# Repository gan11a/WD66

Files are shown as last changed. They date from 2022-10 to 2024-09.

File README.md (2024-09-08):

# WD66 ver 0.1

# As of 12/21/2023 PCB is finished, and tested.

# Witch Doctor 66 is a 65% mechanical keyboard, with layout similar to Leopold FC660M. The idea is to make it compatible with Leopold's case if you don't solder in 2 switches. I want this project to live beyond group buy (if it will ever happen), hence secondary function of PCB to be a drop-in replacement into Leopold. You can find pictures of implemented layouts and layouts planed below, as well as pictures of the PCB.
<h2>
<p align="center">
Layouts:
</p>
</h2>


<h2>
<p align="center">
PCB renders:
</p>
</h2>
<p align="center">


</p>
<h2>
<p align="center">
Photos:
</p>
</h2>
<p align="center">


</p>

# You are welcome to fork, modify and produce it on your own, that said I would like to be in the know about production for profit (dm me on discord: gan1a#5261); also don't be an a*s, don't erase solder mask art))). Rough to-do list is below.

# For ongoing development and planed features please refer to the [issues](https://github.com/gan11a/WD66/issues) page of WD66 Repository.

# Huge thanks to my friends FOXY and ANV3R for supporting me through this project.

# By <a href="https://11customs.com">11customs</a>

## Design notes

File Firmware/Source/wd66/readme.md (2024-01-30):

# wd66

wd66

# default layout:
layout

* Keyboard Maintainer: [11customs](https://github.com/gan11a)
* Hardware Supported: wd66_rev1
* Hardware Availability: *shop not running yet*

Make example for this keyboard (after setting up your build environment):

    make wd66:default

Flashing example for this keyboard:

    make wd66:default:flash

See the [build environment setup](https://docs.qmk.fm/#/getting_started_build_tools) and the [make instructions](https://docs.qmk.fm/#/getting_started_make_guide) for more information. Brand new to QMK? Start with our [Complete Newbs Guide](https://docs.qmk.fm/#/newbs).

## Bootloader

Enter the bootloader in 3 ways:

* **Bootmagic reset**: *not implemented yet*
* **Physical reset button**: Briefly press the button on the back of the PCB near the spacebar.
* **Keycode in layout**: *not implemented yet*

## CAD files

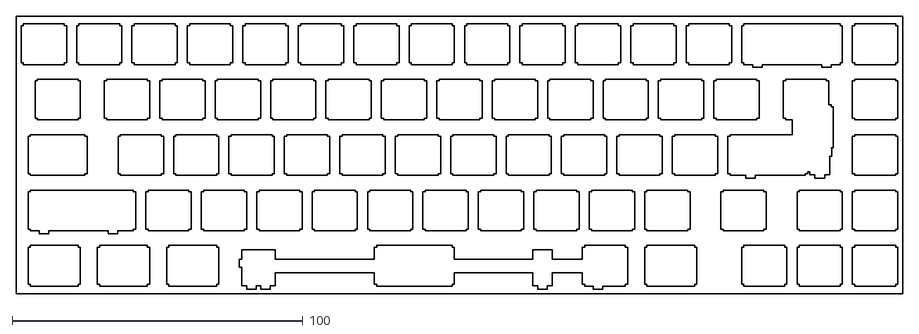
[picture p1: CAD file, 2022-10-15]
Plate/84455f1f9d11c78b356b71624a2b0eeafa77bcbd_switch.dxf
304.8 x 95.2

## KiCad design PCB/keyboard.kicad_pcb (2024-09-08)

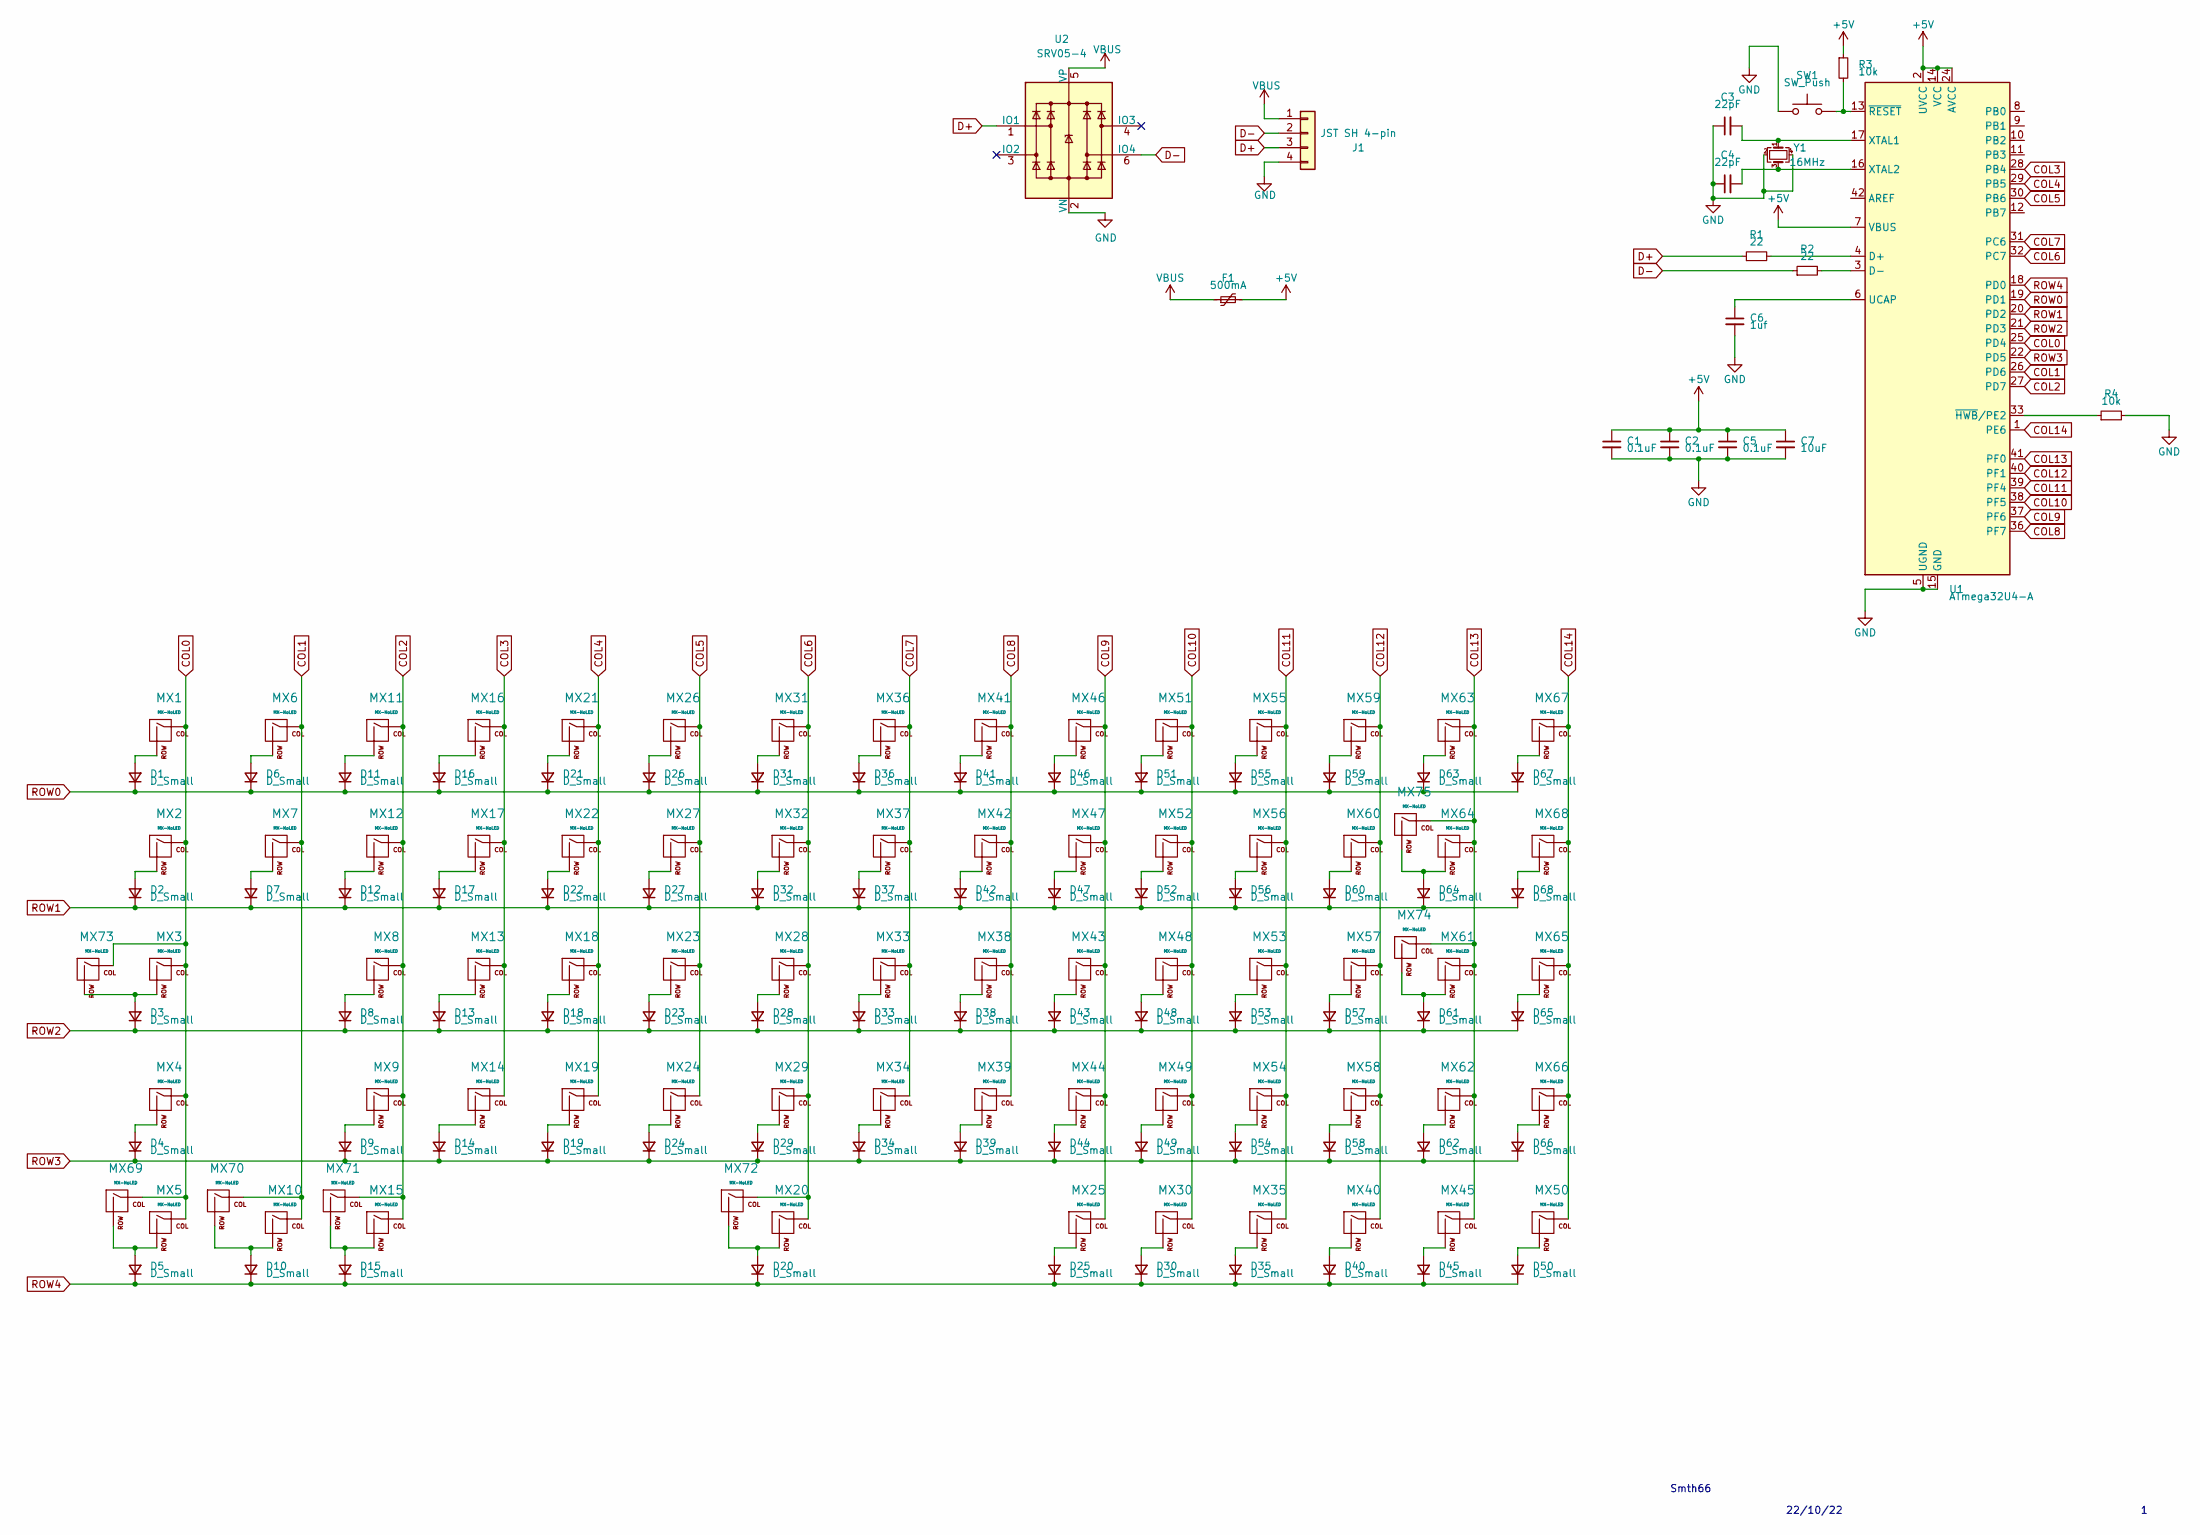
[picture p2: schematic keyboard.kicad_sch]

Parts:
C1, C2, C5: 0.1uF; C_0805_2012Metric
C3, C4: 22pF; C_0805_2012Metric
C6: 1uf; C_0805_2012Metric
C7: 10uF; C_0805_2012Metric
D1, D2, D3, D4, D5, D6, D7, D8, D9, D10, D11, D12, D13, D14, D15, D16, D17, D18, D19, D20, D21, D22, D23, D24, D25, D26, D27, D28, D29, D30, D31, D32, D33, D34, D35, D36, D37, D38, D39, D40, D41, D42, D43, D44, D45, D46, D47, D48, D49, D50, D51, D52, D53, D54, D55, D56, D57, D58, D59, D60, D61, D62, D63, D64, D65, D66, D67, D68: D_Small; D_SOD-123
F1: 500mA; Fuse_1206_3216Metric
J1: JST SH 4-pin; JST_SH_SM04B-SRSS-TB_1x04-1MP_P1.00mm_Horizontal; LCSC Part # C160404
MX1, MX6, MX7, MX8, MX9, MX10, MX11, MX12, MX13, MX14, MX16, MX17, MX18, MX19, MX21, MX22, MX23, MX24, MX26, MX27, MX28, MX29, MX31, MX32, MX33, MX34, MX36, MX37, MX38, MX39, MX40, MX41, MX42, MX43, MX44, MX45, MX46, MX47, MX48, MX49, MX50, MX51, MX52, MX53, MX54, MX55, MX56, MX57, MX59, MX60, MX62, MX65, MX66, MX67, MX68, MX70, MX75: MX-NoLED; MXOnly-1U-NoLED
MX2, MX64, MX69, MX71: MX-NoLED; MXOnly-1.5U-NoLED
MX3: MX-NoLED; MXOnly-1.75U-NoLED
MX4, MX58, MX61: MX-NoLED; MXOnly-2.25U-NoLED
MX5, MX15, MX25, MX30, MX35: MX-NoLED; MXOnly-1.25U-NoLED
MX20: MX-NoLED; MXOnly-6.25U-ReversedStabilizers-NoLED
MX63: MX-NoLED; MXOnly-2U-NoLED
MX72: MX-NoLED; MXOnly-7U-ReversedStabilizers-NoLED
MX73: MX-NoLED; SW_MX_1.75u_stp
MX74: MX-NoLED; MXOnly-ISO-ReversedStabilizers-NoLED
R1, R2: 22; R_0805_2012Metric
R3, R4: 10k; R_0805_2012Metric
SW1: SW_Push; SKQG-1155865
U1: ATmega32U4-A; TQFP-44_10x10mm_P0.8mm
U2: SRV05-4; SOT-23-6-routable; LCSC Part # C85364
Y1: 16MHz; Crystal_SMD_3225-4Pin_3.2x2.5mm

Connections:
+5V: C1.1, C2.1, C5.1, C7.1, F1.2, R3.1, U1.2 (UVCC), U1.7 (VBUS), U1.14 (VCC), U1.24 (AVCC), U1.34 (VCC), U1.44 (AVCC)
COL0: MX1.1 (COL), MX2.1 (COL), MX3.1 (COL), MX4.1 (COL), MX5.1 (COL), MX69.1 (COL), MX73.1 (COL), U1.25 (PD4)
COL1: MX6.1 (COL), MX7.1 (COL), MX10.1 (COL), MX70.1 (COL), U1.26 (PD6)
COL2: MX8.1 (COL), MX9.1 (COL), MX11.1 (COL), MX12.1 (COL), MX15.1 (COL), MX71.1 (COL), U1.27 (PD7)
COL3: MX13.1 (COL), MX14.1 (COL), MX16.1 (COL), MX17.1 (COL), U1.28 (PB4)
COL4: MX18.1 (COL), MX19.1 (COL), MX21.1 (COL), MX22.1 (COL), U1.29 (PB5)
COL5: MX23.1 (COL), MX24.1 (COL), MX26.1 (COL), MX27.1 (COL), U1.30 (PB6)
COL6: MX20.1 (COL), MX28.1 (COL), MX29.1 (COL), MX31.1 (COL), MX32.1 (COL), MX72.1 (COL), U1.32 (PC7)
COL7: MX33.1 (COL), MX34.1 (COL), MX36.1 (COL), MX37.1 (COL), U1.31 (PC6)
COL8: MX38.1 (COL), MX39.1 (COL), MX41.1 (COL), MX42.1 (COL), U1.36 (PF7)
COL9: MX25.1 (COL), MX43.1 (COL), MX44.1 (COL), MX46.1 (COL), MX47.1 (COL), U1.37 (PF6)
COL10: MX30.1 (COL), MX48.1 (COL), MX49.1 (COL), MX51.1 (COL), MX52.1 (COL), U1.38 (PF5)
COL11: MX35.1 (COL), MX53.1 (COL), MX54.1 (COL), MX55.1 (COL), MX56.1 (COL), U1.39 (PF4)
COL12: MX40.1 (COL), MX57.1 (COL), MX58.1 (COL), MX59.1 (COL), MX60.1 (COL), U1.40 (PF1)
COL13: MX45.1 (COL), MX61.1 (COL), MX62.1 (COL), MX63.1 (COL), MX64.1 (COL), MX74.1 (COL), MX75.1 (COL), U1.41 (PF0)
COL14: MX50.1 (COL), MX65.1 (COL), MX66.1 (COL), MX67.1 (COL), MX68.1 (COL), U1.1 (PE6)
GND: C1.2, C2.2, C3.1, C4.1, C5.2, C6.2, C7.2, J1.4, R4.2, SW1.1, U1.5 (UGND), U1.15 (GND), U1.23 (GND), U1.35 (GND), U1.43 (GND), U2.2 (VN), Y1.2, Y1.4
unnamed: D1.2 (A), MX1.2 (ROW)
unnamed: D2.2 (A), MX2.2 (ROW)
unnamed: D3.2 (A), MX3.2 (ROW), MX73.2 (ROW)
unnamed: D4.2 (A), MX4.2 (ROW)
unnamed: D5.2 (A), MX5.2 (ROW), MX69.2 (ROW)
unnamed: D6.2 (A), MX6.2 (ROW)
unnamed: D7.2 (A), MX7.2 (ROW)
unnamed: D8.2 (A), MX8.2 (ROW)
unnamed: D9.2 (A), MX9.2 (ROW)
unnamed: D10.2 (A), MX10.2 (ROW), MX70.2 (ROW)
unnamed: D11.2 (A), MX11.2 (ROW)
unnamed: D12.2 (A), MX12.2 (ROW)
unnamed: D13.2 (A), MX13.2 (ROW)
unnamed: D14.2 (A), MX14.2 (ROW)
unnamed: D15.2 (A), MX15.2 (ROW), MX71.2 (ROW)
unnamed: D16.2 (A), MX16.2 (ROW)
unnamed: D17.2 (A), MX17.2 (ROW)
unnamed: D18.2 (A), MX18.2 (ROW)
unnamed: D19.2 (A), MX19.2 (ROW)
unnamed: D20.2 (A), MX20.2 (ROW), MX72.2 (ROW)
unnamed: D21.2 (A), MX21.2 (ROW)
unnamed: D22.2 (A), MX22.2 (ROW)
unnamed: D23.2 (A), MX23.2 (ROW)
unnamed: D24.2 (A), MX24.2 (ROW)
unnamed: D25.2 (A), MX25.2 (ROW)
unnamed: D26.2 (A), MX26.2 (ROW)
unnamed: D27.2 (A), MX27.2 (ROW)
unnamed: D28.2 (A), MX28.2 (ROW)
unnamed: D29.2 (A), MX29.2 (ROW)
unnamed: D30.2 (A), MX30.2 (ROW)
unnamed: D31.2 (A), MX31.2 (ROW)
unnamed: D32.2 (A), MX32.2 (ROW)
unnamed: D33.2 (A), MX33.2 (ROW)
unnamed: D34.2 (A), MX34.2 (ROW)
unnamed: D35.2 (A), MX35.2 (ROW)
unnamed: D36.2 (A), MX36.2 (ROW)
unnamed: D37.2 (A), MX37.2 (ROW)
unnamed: D38.2 (A), MX38.2 (ROW)
unnamed: D39.2 (A), MX39.2 (ROW)
unnamed: D40.2 (A), MX40.2 (ROW)
unnamed: D41.2 (A), MX41.2 (ROW)
unnamed: D42.2 (A), MX42.2 (ROW)
unnamed: D43.2 (A), MX43.2 (ROW)
unnamed: D44.2 (A), MX44.2 (ROW)
unnamed: D45.2 (A), MX45.2 (ROW)
unnamed: D46.2 (A), MX46.2 (ROW)
unnamed: D47.2 (A), MX47.2 (ROW)
unnamed: D48.2 (A), MX48.2 (ROW)
unnamed: D49.2 (A), MX49.2 (ROW)
unnamed: D50.2 (A), MX50.2 (ROW)
unnamed: D51.2 (A), MX51.2 (ROW)
unnamed: D52.2 (A), MX52.2 (ROW)
unnamed: D53.2 (A), MX53.2 (ROW)
unnamed: D54.2 (A), MX54.2 (ROW)
unnamed: D55.2 (A), MX55.2 (ROW)
unnamed: D56.2 (A), MX56.2 (ROW)
unnamed: D57.2 (A), MX57.2 (ROW)
unnamed: D58.2 (A), MX58.2 (ROW)
unnamed: D59.2 (A), MX59.2 (ROW)
unnamed: D60.2 (A), MX60.2 (ROW)
unnamed: D61.2 (A), MX61.2 (ROW), MX74.2 (ROW)
unnamed: D62.2 (A), MX62.2 (ROW)
unnamed: D63.2 (A), MX63.2 (ROW)
unnamed: D64.2 (A), MX64.2 (ROW), MX75.2 (ROW)
unnamed: D65.2 (A), MX65.2 (ROW)
unnamed: D66.2 (A), MX66.2 (ROW)
unnamed: D67.2 (A), MX67.2 (ROW)
unnamed: D68.2 (A), MX68.2 (ROW)
unnamed: C6.1, U1.6 (UCAP)
unnamed: C3.2, U1.17 (XTAL1), Y1.1
unnamed: C4.2, U1.16 (XTAL2), Y1.3
unnamed: R4.1, U1.33 (~HWB/PE2)
unnamed: R3.2, SW1.2, U1.13 (~RESET)
ROW0: D1.1 (K), D6.1 (K), D11.1 (K), D16.1 (K), D21.1 (K), D26.1 (K), D31.1 (K), D36.1 (K), D41.1 (K), D46.1 (K), D51.1 (K), D55.1 (K), D59.1 (K), D63.1 (K), D67.1 (K), U1.19 (PD1)
ROW1: D2.1 (K), D7.1 (K), D12.1 (K), D17.1 (K), D22.1 (K), D27.1 (K), D32.1 (K), D37.1 (K), D42.1 (K), D47.1 (K), D52.1 (K), D56.1 (K), D60.1 (K), D64.1 (K), D68.1 (K), U1.20 (PD2)
ROW2: D3.1 (K), D8.1 (K), D13.1 (K), D18.1 (K), D23.1 (K), D28.1 (K), D33.1 (K), D38.1 (K), D43.1 (K), D48.1 (K), D53.1 (K), D57.1 (K), D61.1 (K), D65.1 (K), U1.21 (PD3)
ROW3: D4.1 (K), D9.1 (K), D14.1 (K), D19.1 (K), D24.1 (K), D29.1 (K), D34.1 (K), D39.1 (K), D44.1 (K), D49.1 (K), D54.1 (K), D58.1 (K), D62.1 (K), D66.1 (K), U1.22 (PD5)
ROW4: D5.1 (K), D10.1 (K), D15.1 (K), D20.1 (K), D25.1 (K), D30.1 (K), D35.1 (K), D40.1 (K), D45.1 (K), D50.1 (K), U1.18 (PD0)
VBUS: F1.1, J1.1, U2.5 (VP)

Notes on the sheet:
Smth66
22/10/22

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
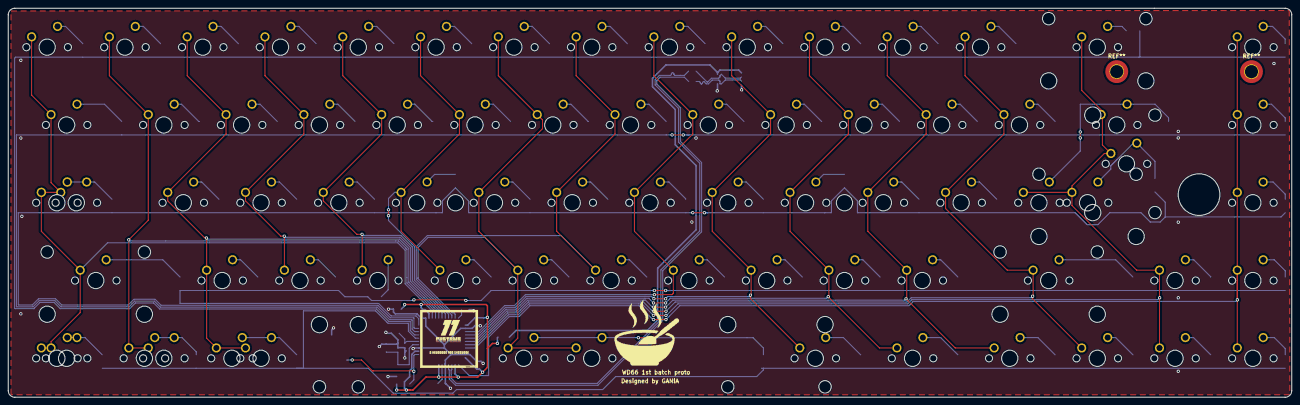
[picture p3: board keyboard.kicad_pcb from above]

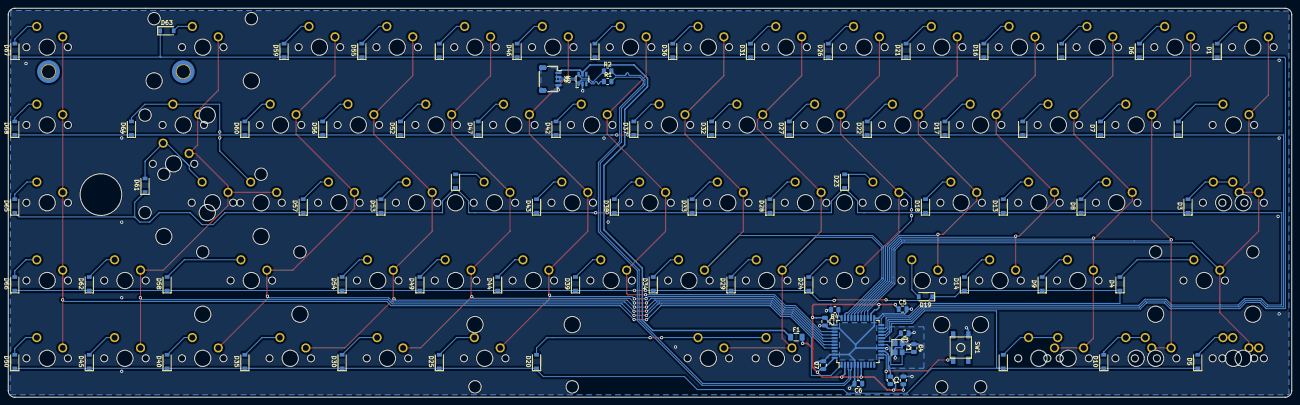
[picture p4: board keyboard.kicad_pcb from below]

Board: 2 copper layers, 314.3 x 95.3 mm, 160 parts (85 on the bottom side), 98 nets.

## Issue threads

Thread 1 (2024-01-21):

Big stand-off hole doesn't align with the stand-off on fc660m case.

gan11a, 2024-01-21:
>Title

gan11a, 2024-01-26:
Moved the hole

Closed 2024-01-26.

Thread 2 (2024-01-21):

Daughterboard doesn't have any mounting and is too thick for fc660m implementation.

gan11a, 2024-01-21:
> Title
Refer to personal obsidian doc for possible solution and other documentation.

gan11a, 2024-01-26:
Added a cutout for daughterboard

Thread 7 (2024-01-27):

Rework the hole firmware and add to QMK

gan11a, 2024-01-27:
>title

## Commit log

2022-10-22 Changed PCB Design
    [keyboard.kicad_pcb]
2022-10-22 fixed pcb folder
    [Soyuz65.kicad_pcb]
2022-10-22 configured footprints
    [keyboard.kicad_pcb, keyboard.kicad_sch]
2022-10-22 created MCU schematic
    [keyboard.kicad_sch]
2022-10-23 added USB and Switch to schematic
    [keyboard.kicad_sch]
2022-10-23 added switch grid to schematic
    [keyboard.kicad_sch]
2022-11-02 Finnished Schematic????
    [keyboard.kicad_sch]
2022-11-04 Started pcb development
    [keyboard.kicad_pcb]
2022-11-04 still working on pcb
2022-11-05 fixed footprints
    [keyboard.kicad_pcb, keyboard.kicad_sch]
2022-11-05 PCB work in progress
    [keyboard.kicad_pcb, keyboard.kicad_sch]
2022-11-06 mocked up pcb
    [keyboard.kicad_pcb]
2022-11-08 updated schematic to work with unified daughterboard
    [keyboard.kicad_sch]
2022-11-10 changed pcb to work with unified daughterboard
    [keyboard.kicad_pcb, keyboard.kicad_sch]
2022-11-20 Working on traces
    [keyboard.kicad_pcb, keyboard.kicad_sch]
2022-11-21 finnished traces
    [keyboard.kicad_pcb, keyboard.kicad_sch]
2022-11-26 Finished PCB designed, still not tested
    [keyboard.kicad_pcb]
2022-12-06 added holes for center standoffs
    [keyboard.kicad_pcb]
2022-12-06 updated silkscreen
    [keyboard.kicad_pcb]
2022-12-27 started redoing wiring
    [keyboard.kicad_pcb, keyboard.kicad_sch]
2022-12-27 all new pretty wiring
    [keyboard.kicad_pcb, keyboard.kicad_sch]
2022-12-29 added a hole
2023-01-07 smoothed out the wiring
2023-01-09 Redid wiring again
    [keyboard.kicad_sch]
2023-01-09 Differential pair done
    [keyboard.kicad_sch]
2023-01-16 started reworking wiring (again), only mx footprints now
    [keyboard.kicad_sch]
2023-01-16 redid wiring (again) no checks yet
    [keyboard.kicad_pcb, keyboard.kicad_sch]
2023-01-17 still working on wiring
    [keyboard.kicad_pcb]
2023-01-19 finnished implementing layouts
    [keyboard.kicad_pcb]
2023-01-23 relocated JST
    [keyboard.kicad_pcb]
2023-01-28 trying production
    [keyboard.kicad_pcb]
2023-12-21 production files and last small changes to v0.1
    [keyboard-CuBottom.gbr, keyboard-CuTop.gbr, keyboard-EdgeCuts.gbr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]
2024-01-26 started fixing daughterboard mount
    [keyboard.kicad_pcb]
2024-09-08 changes to v1.5 pcb
    [keyboard.kicad_pcb]
2024-09-08 added mounting for new uDB
    [keyboard.kicad_pcb]
